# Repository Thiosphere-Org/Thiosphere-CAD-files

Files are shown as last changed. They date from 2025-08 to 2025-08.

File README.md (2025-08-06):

# Modular Open Source Spaces
We have formatted our world for cars, yet have little else to make use of all that space we have given over to these machines. A Thiosphere™ is created to fill that void with a purpose and beauty that defines its bold and efficient design. It is Open Source Hardware that anyone can build and modify to their own needs. 

## Introduction

One thiosphere is made from the fewest number of parts possible, yet resulting in a strong, light and roomy, modular space that only take up 1/2 of a parking spot. It is flat packable and can be assembled with common tools. It is a modular so you can create a endless number of spaces, from a simple shelter to a complex office. It is both functional and beautiful, and designed to be a second place for life to flourish - whatever, and wherever those requirments are.

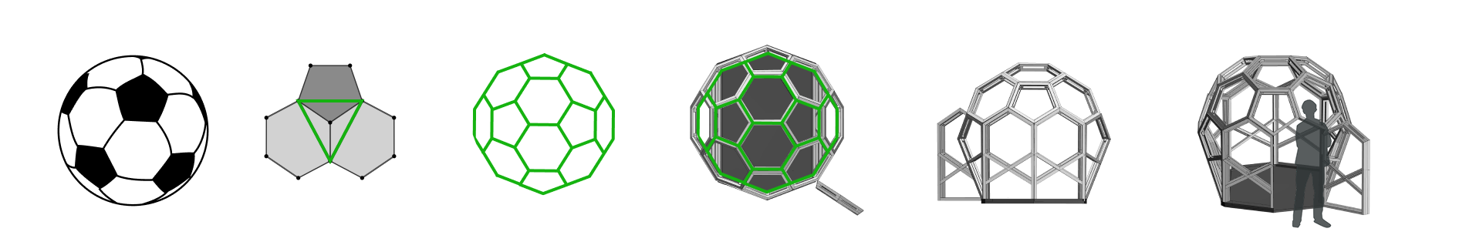
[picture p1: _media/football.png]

Thiosphere Basics
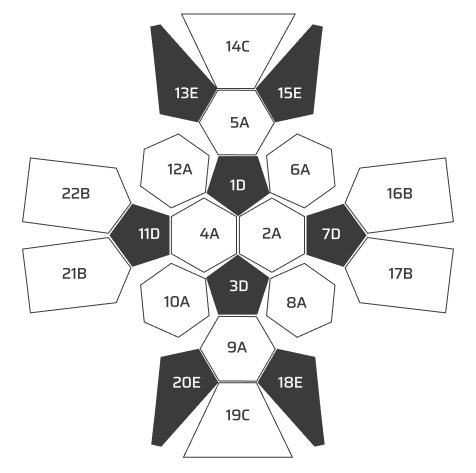
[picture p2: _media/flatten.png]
Thiosphere Flattened View


### Open Source Spaces
Understanding Our Open Hardware License
The CERN Open Hardware License (Version 2 - Strongly Reciprocal) ensures that:

- All designs and modifications must be shared openly
- Commercial use is permitted with proper attribution
- Modified versions must be shared under the same license
- Original creators must be credited
- Documentation must be provided for all changes

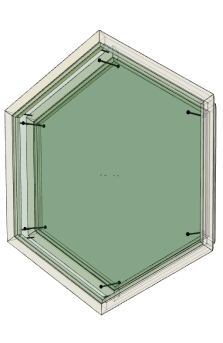
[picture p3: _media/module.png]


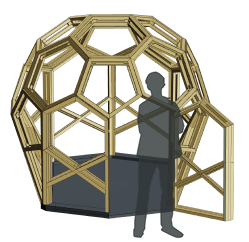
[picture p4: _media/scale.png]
Thiosphere Scale


## The Advantages

- **Built Strong**: Spherical geometry = maximum strength, minimum material
- **Stays Cool**: Natural convection keeps the environment stable inside
- **Fits Right In**: Designed for existing parking spaces - no modifications needed
- **Easy to Build**: Simple geometry means you can make it locally with basic tools
- **Energy Smart**: Passive design cuts energy needs by 80%

## What's a Thios?

> The number two in Greek is written as "δύο" and pronounced with a soft "th" sound (thío), rather than the hard "d" one might expect. This "thio" prefix perfectly describes the dual-sphere design of the Thiosphere™, a second place for life.

## Construction Guide

### What You'll Need

**Materials:**
- 180 - 2x4's
- 4 - 4'x8' sheets of plywood
- 120 - nuts and bolts
- 800 - wood screws
- 4 casters, a small trailer or a leveling plinth (optional)

**Tools:**
- Compound miter saw
- Table saw or circular saw
- Drill/driver
- Measuring tape
- Pencil
- Safety gear (glasses, hearing protection)

### Step-by-Step Build

#### 1. Prep Your Wood

**Cut 2x4s to length:**
- **Outer dome**: 20.67" edge pieces
- **Inner dome**: 19.38" edge pieces

**Rip 2x4s for edge pieces:**
- Set table saw to 19.8° bevel angle
- Rip 2x4s to create angled edge pieces
- You'll need about 60 pieces for outer dome, 60 for inner dome

#### 2. Cut Those Angles

**For Outer Dome (8' diameter):**
- **Hexagon to hexagon joints**: 20.91° compound angle
- **Hexagon to pentagon joints**: 18.69° compound angle
- **Hexagon joins**: 30° angle
- **Pentagon joins**: 36° angle

**For Inner Dome (7.5' diameter):**
- Same angles as outer dome
- All pieces are shorter (19.38" vs 20.67")

#### 3. Put It Together

**Start with the base ring:**
1. Lay out your first ring of pieces on a flat surface
2. Join pieces using the calculated angles
3. Use GRK screws to secure joints
4. Check for roundness and adjust as needed

**Build upward in rings:**
1. Each ring connects to the one below
2. Keep consistent spacing between inner and outer domes
3. Use temporary supports to hold pieces in place
4. Work in sections to keep it solid

#### 4. Add the Panels

**Cut plywood panels:**
- Measure each opening between frame pieces
- Cut panels to fit with 1/4" gap for expansion
- Sand edges smooth

**Install panels:**
1. Apply silicone caulk to frame edges
2. Press panels into place
3. Secure with screws around perimeter
4. Wipe excess caulk

#### 5. Weatherproof It

**Seal all joints:**
- Apply silicone caulk to all exterior joints
- Pay special attention to panel edges
- Let it cure for 24 hours

**Apply finish:**
- Paint or seal all wood surfaces
- Use exterior-grade paint for outside use
- Apply multiple coats for durability

### Pro Tips

- **Take your time**: Precision in cutting angles is key
- **Test fit**: Dry assemble sections before final assembly
- **Use jigs**: Create simple jigs to hold pieces at correct angles
- **Work in pairs**: Some assembly steps are easier with help
- **Check measurements**: Verify each piece before cutting

### Resources

- [Compound Miter Saw Calculator](https://jansson.us/jcompound.html) - Essential for calculating precise angles
- [GRK FIN/Trim™ Screws](https://grkfasteners.ca/product/fin-trim-finishing-trim-head-screw/) - Recommended for clean finish
- [McMaster-Carr Hardware](https://www.mcmaster.com/90273A572/) - For additional fasteners and hardware

### Quick Reference

Outer Dome (8' diameter):
- Edge length: 20.67"
- Pentagon diameter: 23.88"
- Hexagon diameter: 35.18"

Inner Dome (7.5' diameter):
- Edge length: 19.38"
- Pentagon diameter: 32.98"
- Hexagon diameter: 22.38"

Key Angles:
- Hex to hex: 20.91°
- Hex to penta: 18.69°
- Hex joins: 30°
- Penta joins: 36°
- 2x4 rip angle: 19.8°

Thoispheres - Domus Opus Est, (the work of creating space is never ending).

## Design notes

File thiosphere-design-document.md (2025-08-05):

# **Thiosphere Design Document**

**Version 0.1 | Modular Open Source Space**

---

## **Executive Summary**

The Thiosphere™ is an open source hardware shelter system designed to create modular, efficient spaces that address the underutilization of urban infrastructure. Built on the principle "Domus Opus Est" (the work of creating space is never ending), the Thiosphere offers a standardized, flat-packable solution that transforms half a parking space into functional, beautiful environments for work, shelter, or community use.

## **Project Vision**

### **Core Philosophy**

We have formatted our world for automobiles, dedicating vast amounts of urban space to parking and vehicle infrastructure while leaving communities with limited options for affordable, flexible spaces. The Thiosphere addresses this imbalance by providing an open source solution that reclaims and repurposes underutilized space.

### **Design Principles**

* **Modularity**: Infinitely expandable and configurable  
* **Accessibility**: Buildable with common tools and materials  
* **Efficiency**: Maximum utility from minimal footprint  
* **Beauty**: Functional aesthetics that enhance environments  
* **Openness**: Fully open source hardware design  
* **Adaptability**: Customizable for diverse use cases

## **Technical Specifications**

### **Dimensional Standards**

* **Footprint**: 1/2 standard parking space (approximately 4' x 9')  
* **Height**: Variable based on configuration  
* **Weight**: Lightweight construction for portability  
* **Modularity**: Standardized connection points for expansion

### **Materials List (Single Unit)**

* **Structural**: 180 pieces of 2x4 lumber  
* **Skin**: 4 sheets of 4'x8' plywood  
* **Hardware**:  
  * 120 nuts and bolts  
  * 800 wood screws  
* **Mobility** (Optional):  
  * 4 casters  
  * Small trailer attachment  
  * Leveling plinth system

### **Required Tools**

* Table saw  
* Miter saw  
* Power drill  
* Standard hand tools  
* Safety equipment

## **Design Architecture**

### **Structural System**

The Thiosphere employs a dual-sphere design philosophy, creating primary and secondary spaces that can function independently or in harmony. The structural framework utilizes standard dimensional lumber in a modular connection system that prioritizes:

* **Strength**: Engineered joints and bracing  
* **Lightness**: Optimized material usage  
* **Assembly**: Tool-friendly connections  
* **Disassembly**: Reversible construction methods

### **Modular Framework**

The system is designed around standardized connection points that allow for:

* **Linear expansion**: Creating corridors and extended spaces  
* **Vertical stacking**: Multi-level configurations  
* **Angular connections**: Complex spatial arrangements  
* **Hybrid configurations**: Integration with existing structures

### **Envelope System**

The exterior skin system provides:

* **Weather protection**: Durable plywood construction  
* **Thermal performance**: Insulation-ready cavities  
* **Aesthetic flexibility**: Customizable finishes  
* **Maintenance access**: Replaceable panels

## **Use Case Applications**

### **Primary Applications**

1. **Emergency Shelter**: Rapid deployment housing solutions  
2. **Workspace**: Pop-up offices and creative studios  
3. **Community Spaces**: Meeting areas and social hubs  
4. **Retail**: Temporary or permanent vendor spaces  
5. **Educational**: Outdoor classrooms and workshops

### **Secondary Applications**

1. **Storage**: Secure, weatherproof storage solutions  
2. **Recreation**: Garden houses, hobby spaces  
3. **Healthcare**: Mobile clinic expansions  
4. **Events**: Festival and market structures  
5. **Research**: Field stations and monitoring posts

## **Open Source Framework**

### **Licensing**

The Thiosphere operates under the **CERN Open Hardware License Version 2 \- Strongly Reciprocal**, ensuring:

* **Open Modification**: All designs freely modifiable  
* **Attribution Requirements**: Original creator credit mandatory  
* **Reciprocal Sharing**: Modifications must be openly shared  
* **Commercial Compatibility**: Commercial use permitted with compliance  
* **Documentation Standards**: All changes must be documented

### **Repository Structure**

Thiosphere-CAD-files/  
├── structural/  
│   ├── frame-components/  
│   ├── connection-details/  
│   └── assembly-sequences/  
├── envelope/  
│   ├── panel-designs/  
│   ├── window-door-systems/  
│   └── finish-options/  
├── documentation/  
│   ├── build-instructions/  
│   ├── modification-guides/  
│   └── safety-protocols/  
└── community/  
    ├── user-modifications/  
    ├── build-logs/  
    └── troubleshooting/

### **Community Engagement**

* **Discord Server**: Real-time collaboration and support  
* **GitHub Issues**: Bug tracking and feature requests  
* **Wiki Documentation**: Community-maintained knowledge base  
* **Build Showcases**: User project galleries

## **Manufacturing & Assembly**

### **Fabrication Strategy**

The Thiosphere is designed for distributed manufacturing using:

* **Local Materials**: Standard lumber yard inventory  
* **Common Tools**: Accessible workshop equipment  
* **Batch Production**: Efficient cut lists and workflows  
* **Quality Control**: Standardized tolerances and checks

### **Assembly Process**

1. **Preparation**: Material sorting and quality inspection  
2. **Fabrication**: Component cutting and preparation  
3. **Pre-assembly**: Sub-component construction  
4. **Final Assembly**: Structure completion  
5. **Finishing**: Surface treatment and customization  
6. **Testing**: Structural and functional verification

### **Packaging & Distribution**

* **Flat-pack Design**: Minimal shipping volume  
* **Standardized Packaging**: Efficient logistics  
* **Assembly Instructions**: Clear, visual documentation  
* **Support Network**: Community assistance resources

## **Quality & Safety Standards**

### **Structural Requirements**

* **Load Capacity**: Engineered for intended use loads  
* **Wind Resistance**: Regional wind load compliance  
* **Seismic Considerations**: Appropriate regional standards  
* **Connection Integrity**: Redundant fastening systems

### **Safety Protocols**

* **Assembly Safety**: PPE requirements and procedures  
* **Operational Safety**: User guidelines and warnings  
* **Maintenance Safety**: Inspection and repair protocols  
* **Emergency Procedures**: Evacuation and disaster response

### **Testing Standards**

* **Structural Testing**: Load and stress verification  
* **Environmental Testing**: Weather resistance validation  
* **Durability Testing**: Long-term performance assessment  
* **User Testing**: Usability and accessibility validation

## **Economic Model**

### **Cost Structure**

* **Material Costs**: Approximately $X per unit (market dependent)  
* **Labor Costs**: DIY or professional assembly options  
* **Tool Investment**: One-time workshop setup  
* **Maintenance Costs**: Minimal ongoing expenses

### **Value Proposition**

* **Cost Efficiency**: Fraction of traditional construction costs  
* **Time Efficiency**: Rapid deployment capability  
* **Space Efficiency**: Maximum utility per square foot  
* **Investment Recovery**: Multi-use applications and portability

## **Environmental Impact**

### **Sustainability Features**

* **Material Selection**: Sustainable lumber sources preferred  
* **Longevity Design**: Durable construction methods  
* **Recyclability**: End-of-life material recovery  
* **Energy Efficiency**: Passive design strategies

### **Environmental Benefits**

* **Reduced Construction Waste**: Precise material calculations  
* **Urban Density**: Better space utilization  
* **Reduced Transportation**: Local manufacturing  
* **Adaptive Reuse**: Existing space repurposing

## **Development Roadmap**

### **Phase 1: Foundation (Current)**

* \[x\] Core design completion  
* \[x\] Prototype construction  
* \[x\] Open source license implementation  
* \[x\] Community platform establishment

### **Phase 2: Validation (Next 6 months)**

* \[ \] Beta builder program  
* \[ \] Design iteration based on feedback  
* \[ \] Safety and compliance verification  
* \[ \] Documentation refinement

### **Phase 3: Expansion (6-12 months)**

* \[ \] Specialized configurations  
* \[ \] Regional adaptations  
* \[ \] Partnership development  
* \[ \] Commercial service launch

### **Phase 4: Evolution (12+ months)**

* \[ \] Advanced materials integration  
* \[ \] Smart systems compatibility  
* \[ \] Global standardization  
* \[ \] Ecosystem expansion

## **Risk Assessment**

### **Technical Risks**

* **Structural Performance**: Mitigation through engineering validation  
* **Weather Resistance**: Testing in diverse conditions  
* **User Assembly**: Clear documentation and support  
* **Material Availability**: Multiple supplier relationships

### **Business Risks**

* **Market Adoption**: Community building and demonstration  
* **Regulatory Compliance**: Proactive code research  
* **Competition**: Open source advantage and community  
* **Intellectual Property**: Strong license protection

### **Mitigation Strategies**

* **Iterative Development**: Continuous improvement process  
* **Community Feedback**: User-driven enhancements  
* **Professional Partnerships**: Expert consultation  
* **Documentation Excellence**: Comprehensive user support

## **Success Metrics**

### **Quantitative Measures**

* **Build Completions**: Number of successful constructions  
* **Community Growth**: Active users and contributors  
* **Repository Activity**: Commits, issues, and engagement  
* **Cost Reduction**: Percentage savings vs. alternatives

### **Qualitative Measures**

* **User Satisfaction**: Feedback and testimonials  
* **Design Innovation**: Community modifications and improvements  
* **Social Impact**: Problem-solving effectiveness  
* **Ecosystem Health**: Sustainable community growth

## **Conclusion**

The Thiosphere represents a paradigm shift in how we approach spatial challenges in the modern world. By combining open source principles with practical design excellence, we create not just a product, but a movement toward more efficient, beautiful, and accessible built environments.

The project's success depends on community engagement, continuous improvement, and commitment to the open source ethos that makes innovation accessible to all. Through collaborative development and shared knowledge, the Thiosphere can evolve to meet diverse global needs while maintaining its core principles of efficiency, beauty, and openness.

---

**Document Version**: 1.0  
**Last Updated**: August 2025  
**License**: CERN Open Hardware License Version 2 \- Strongly Reciprocal  
**Contact**: [Project Repository](https://github.com/Thiosphere-Org/Thiosphere-CAD-files) | [Community Discord](https://discord.gg/39JH75tCJc)  
**Commercial Support**: [Thios \+ Company](https://thios.co/) (coming soon)

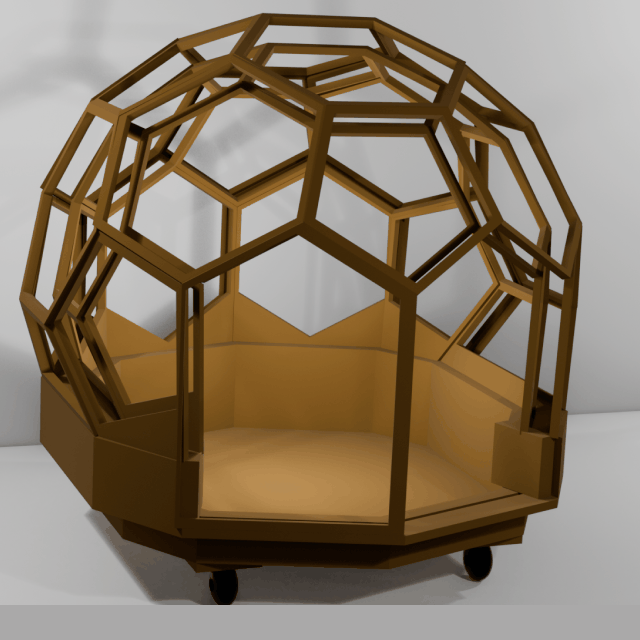
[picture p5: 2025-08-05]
_media/thios-examples.gif

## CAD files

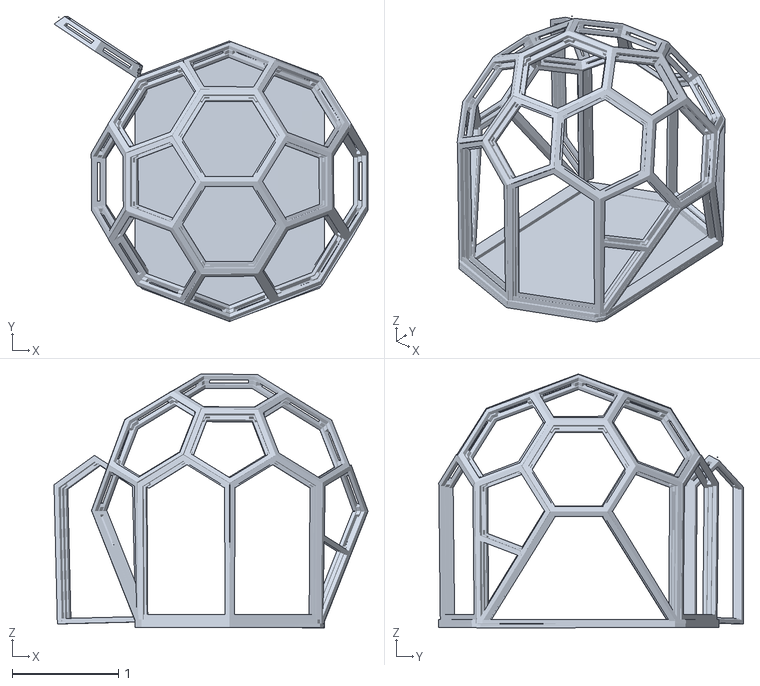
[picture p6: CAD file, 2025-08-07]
src/thiosphere-fine.stl
2.95 x 2.87 x 2.39
